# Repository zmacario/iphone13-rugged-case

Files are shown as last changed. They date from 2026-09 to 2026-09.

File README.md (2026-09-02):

# iPhone 13 Rugged Case — parametric, two-part, 3D-printable

A drop-oriented case for the **iPhone 13 (6.1", 146.7 × 71.5 × 7.65 mm)**, designed to be
printed in **PLA**. It splits into a front frame and a back plate held together by **10 M3
screws running into 10 captive nuts**, so nothing has to stretch over the phone — which is what
makes a rigid filament workable for a case at all.

Everything here is generated by one parametric FreeCAD script, which also re-verifies the model
on every run. The STLs are the output, not the source.

> **Status: printed, and the phone fits.** Both parts have been printed in PLA and the iPhone 13
> seats in them. Every opening — the four button windows, the two bottom slots and the camera —
> comes from measurements taken off printed parts on the actual phone, not from estimates. See
> [What has and hasn't been verified](#what-has-and-hasnt-been-verified) for what is still open.

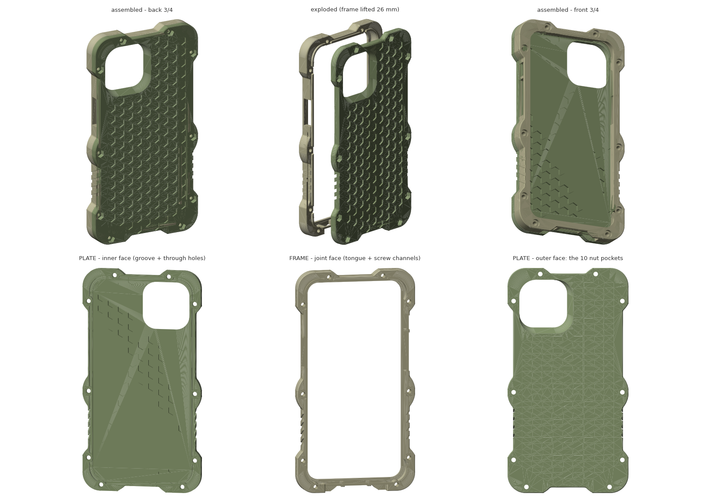
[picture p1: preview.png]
Case renders


| | |
|---|---|
| Assembled | 87.2 × 162.4 × 13.75 mm |
| Material | 60.0 cm³ ≈ **74 g** of PLA (52 g plate + 22 g frame) |
| Hardware | **10 × M3 × 10 mm button head (ISO 7380)** + **10 × M3 nut (DIN 934)** |
| Back plate | 4.0 mm in the middle, 5.0 mm around the rim |
| Side wall | 3.4 mm (2.4 mm at the grip grooves) |
| Corner shell | 4.0 mm plus a 1.6 mm internal air pocket |
| Lens recess | **2.1 mm** below the outer back face |
| Screen lip | 1.8 mm above the display |

## What you need

- ~74 g of filament (PLA works; see *On PLA* below)
- 10 × M3 × 10 mm button-head screws, ISO 7380. **Not countersunk** — a conical head wedges the
  plastic apart as you tighten it and splits thin PLA walls.
- 10 × M3 nuts, DIN 934 (2.4 mm thick, 5.5 mm across flats)
- A 2 mm hex key

## Printing

**Orientation matters and is different for each part. Getting the frame wrong is the single most
common way to ruin this print.**

| Part | File | Orientation |
|---|---|---|
| Back plate | `capa_v8_base_traseira.stl` | Back face down on the bed (honeycomb side down) |
| Front frame | `capa_v8_aro_frontal.stl` | **Upside down — front lip face on the bed** |

The frame's joint face is only 3.4 mm wide. Put that face on the bed and the first layer is a
thin 460 mm-long ring that will lift. Printed lip-down, the first layer is the 4.9 mm-wide rim
ring, and the whole part comes out without a single support.

The plate has a 1 mm skirt around its rim, so it **cannot** be printed inverted either — the
skirt ring would be the lowest feature and the central slab would be cantilevered over air.

| Setting | Value |
|---|---|
| Layer height | 0.2 mm |
| Perimeters | 3–4 |
| Infill | 25–35 % gyroid |
| PLA | 200–215 °C, bed 60 °C, fan 100 % |
| Supports | **None**, for either part |

Printed lip-down, the roofs of the button windows become bridges — the longest is **28.5 mm**
across a 3.4 mm wall. Turn bridging and full part cooling on. Any sag lands on the inner edge of
the window, which is invisible once assembled. Other bridges are short: 1.6 mm over the corner
air pockets, 6.4 mm over each honeycomb cell, 1.4 mm at the nut pocket ceiling.

### Print the test coupons first

`teste_canto_base.stl` + `teste_canto_aro.stl` are the camera corner of both parts, about
40 minutes together. That pair exercises the camera opening, the tongue-and-groove joint, one
screw with its nut and one reinforced corner. It is cheap insurance against a nine-hour print
that turns out not to close, which is exactly how the camera opening was caught.

## Assembly

1. Drop the 10 nuts into the hex pockets on the **back** of the plate. The pockets are
   deliberately tight (5.6 mm for a 5.5 mm nut); if yours come out loose, a dab of glue holds
   them — when you drive the screws, those pockets face down.
2. Drop the phone into the **frame from the back**, screen facing down.
3. Seat the plate. The tongue enters the groove and aligns everything on its own.
4. Drive the 10 screws from the **front rim**: the two mid-side ones first, then the four
   corners crosswise, then top and bottom. The threads are steel now, but what you are
   compressing is PLA — tighten until firm, not until it stops.

If the joint is tight on first assembly, raise `JOINT_GAP` from 0.15 to 0.20 and regenerate. Do
not file the tongue down; it is what keeps the two halves aligned.

## Openings

Distances from the **top** of the phone. Every one of these was measured on a printed part fitted
to the phone — the first two rounds of button windows and the first camera opening were estimates,
and all of them were wrong.

| Opening | Edges | Span |
|---|---|---|
| Mute switch (left side) | 26.00 → 36.50 mm | 10.50 mm |
| Divider between the two left windows | 36.50 → 38.50 mm | 2.00 mm |
| Volume + and − (one window) | 38.50 → 67.00 mm | 28.50 mm |
| Power / side button (right side) | 40.50 → 62.50 mm | 22.00 mm |
| Lightning (bottom, centred) | — | 16.8 × 7.0 mm |
| Speaker / microphone | ±11.0 to ±23.0 mm from centre | 12.00 mm each |
| Camera island | 1.50 mm from the top, 1.50 mm from the side | 34.5 → 38.9 mm |

Volume + and − share a single window on purpose. The real buttons are about 2 mm apart; a divider
that thin would be fragile, and if it landed even slightly off it would sit on a button.

### The camera island is a truncated pyramid

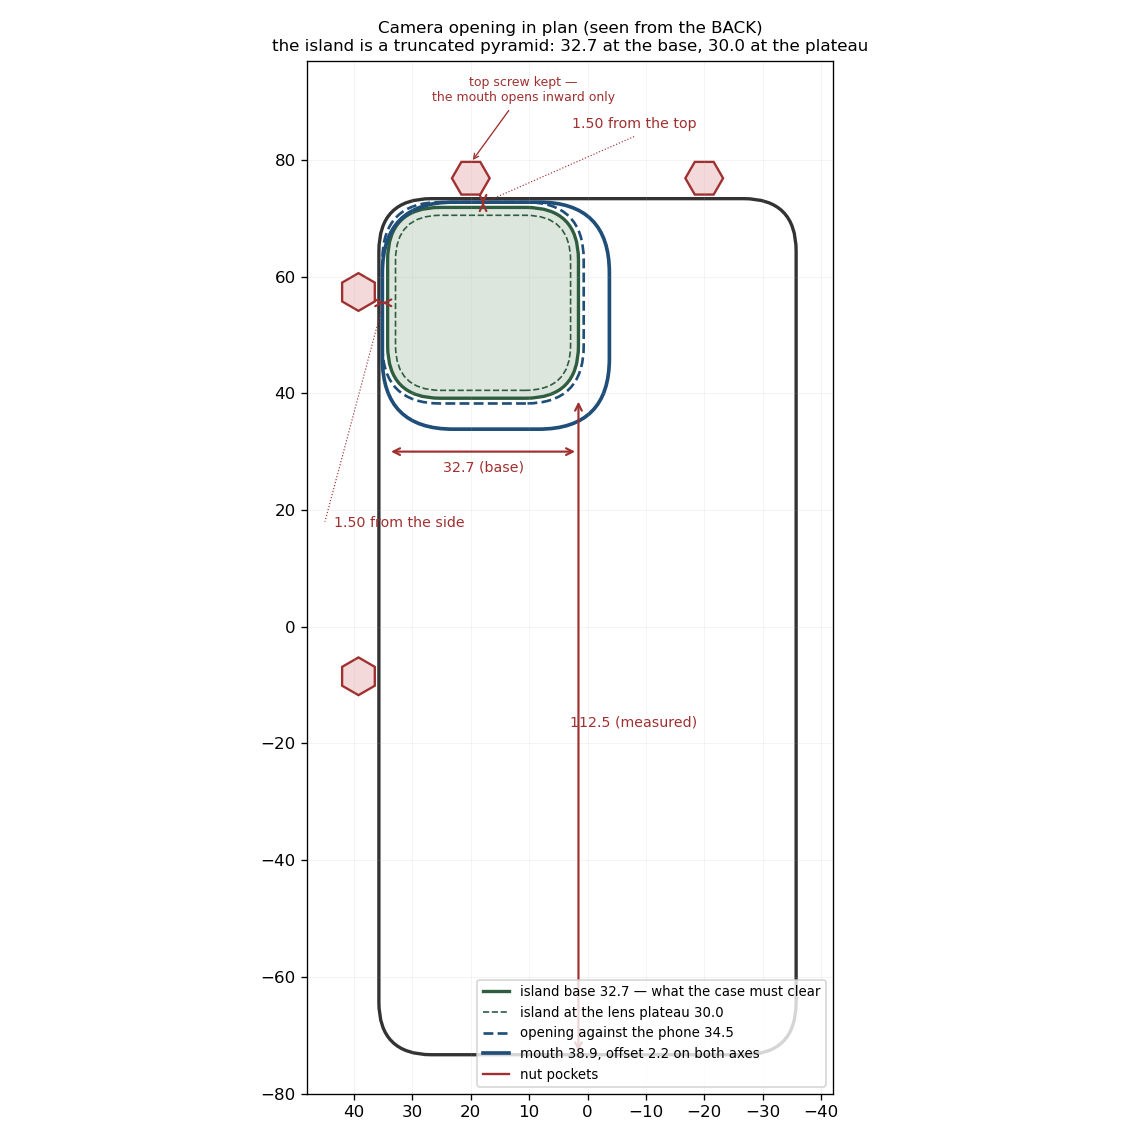
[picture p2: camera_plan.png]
Camera opening in plan


This is the part that took three attempts, and the reason is worth stating plainly: the island is
**30.0 mm square at the lens plateau but 32.7 mm at its base**, where it meets the back glass. The
case has to clear the **base**, and the plateau is the number you get if you measure the obvious
way. Modelling the plateau produced an opening that was both too small and mispositioned, and the
case would not close with the phone in it.

The three measurements close exactly, which is how the numbers were confirmed:
**112.5 + 32.7 + 1.5 = 146.7 mm**.

**The opening flares inward only, on both axes.** It is 34.5 mm against the phone and 38.9 mm at
the outer face, but the mouth is offset 2.2 mm in X *and* Y, so its outer edges sit flush with the
narrow opening's. On the two edges where the island is only 1.5 mm from the edge of the phone
there is no room to flare — that thin band is exactly what carries the corner screw and the top
screw. The mouth opens only toward the centre of the phone, which is the direction the ultra-wide
actually needs clear.

That is what kept all 10 screws. With a symmetric flare the mouth would reach y = 74.95 and eat
the nut pocket of the top screw, which starts at 74.05.

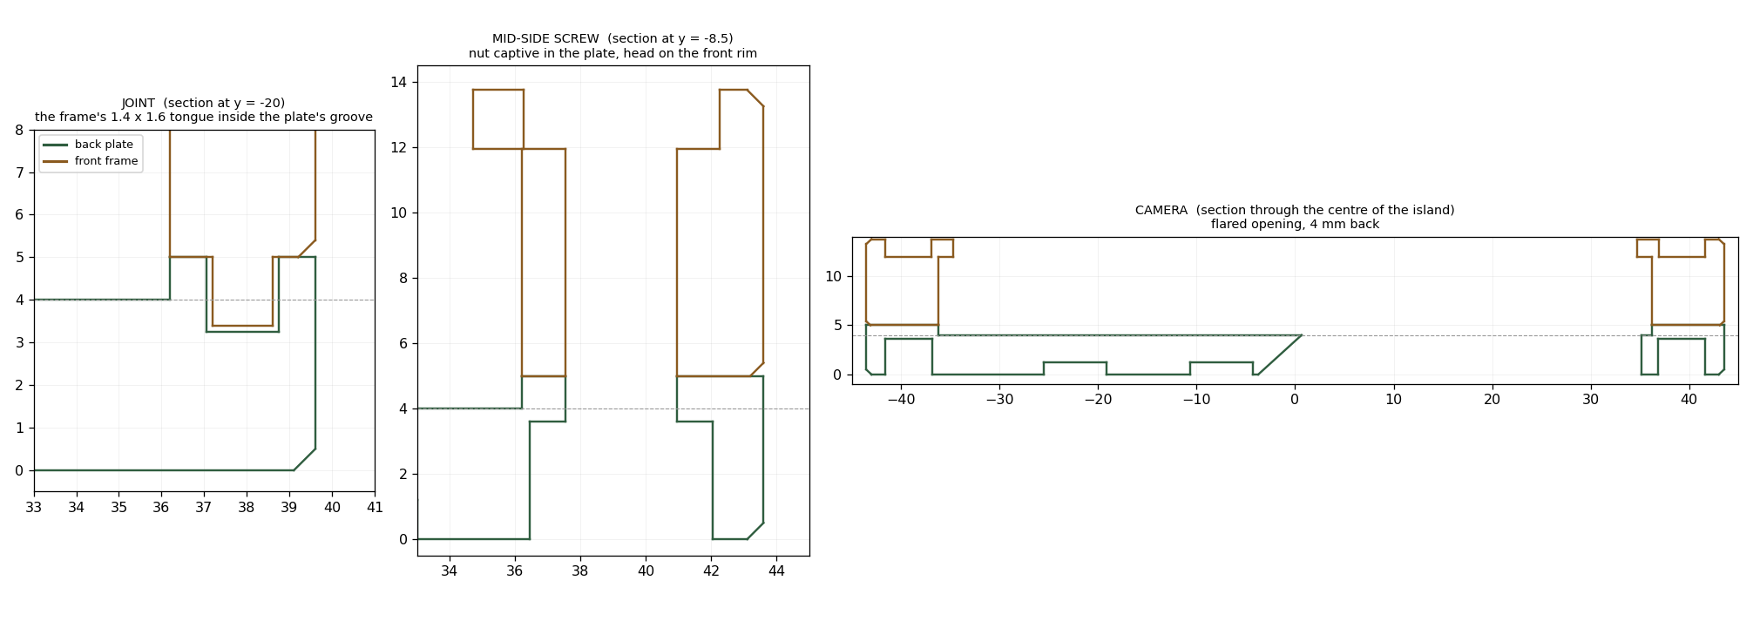
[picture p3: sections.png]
Cross-sections


The asymmetry is visible in the right-hand section above: the opening ramps out on one side and
goes straight up on the other.

**Growing the case does not help** — this was tried and measured, so you don't have to:

| `BUMP` | Case | Wall around the nut pocket |
|---|---|---|
| **4.0 (current)** | **87.2 × 162.4** | **1.2 mm** |
| 5.0 | 89.2 × 164.4 | 0.6 mm |
| 5.75 | 90.7 × 165.9 | 0.8 mm |
| 6.5 | 91.5 × 166.7 | 0.0 mm |

It is counterintuitive, and the reason is in the code: the rule that places each screw keeps it
**centred in the band of material**, so fattening the corner walks the screw outward along with
the surface instead of away from the opening — while the zone where the pad is at full thickness
*shrinks*. At `BUMP` 6.5 the case is 4.3 mm wider and the walls have gone to zero.

## What has and hasn't been verified

| | |
|---|---|
| Both parts print without supports | **yes** |
| The phone seats in the case | **yes** |
| All four button windows line up | **yes**, measured on a printed frame |
| Speaker, microphone and Lightning openings | **yes** |
| Camera opening clears the island and closes | **yes** |
| Nut pockets holding real M3 nuts | not yet confirmed |
| Head recesses taking real screws | not yet confirmed |
| Ultra-wide vignetting at 0.5× | **unverified** — see below |
| Actual drop performance | **never tested.** No one has thrown this at concrete |

The asymmetric flare is a reasoned bet, not a measurement: it assumes the ultra-wide needs
clearance toward the centre of the phone and not toward its two near edges. After assembling,
take a photo at **0.5×** and look at the corners of the frame. If it vignettes, raise `CAM_FLARE`
from 2.2 and regenerate — and then the top screw on the camera side becomes a choice rather than a
given.

The SIM tray is covered — normal for a rugged case. There is no top cutout, and **wireless
charging does not work through this case**: the back is 4.0 mm and Qi wants 3 mm or less between
the charger and the phone. That is a deliberate trade — the same 4 mm is what recesses the lenses.

## Design notes

Almost nothing here is a free choice; each dimension is pinned by something concrete. The
reasons are worth knowing before you modify anything.

**Two parts, split 1 mm above the phone's back plane.** PLA does not stretch, so a one-piece case
cannot be fitted. The phone enters the frame from the back and the plate closes it. The inverse
split (a tub plus a thin front bezel) was rejected on purpose: it would put a face-down drop onto
a thin PLA frame, which is exactly where it breaks. Here the part that takes the impact is the
frame — a closed, stiff ring.

**The plate is a shallow tray, not a flat slab.** It is 4.0 mm in the middle and 5.0 mm around
the rim. The extra millimetre is what gives the nut a ceiling to bear against, and it is only
where the screws are — the middle stays 4.0 mm, because that is what sets the lens recess. It is
added *inward*, by raising the split plane: thickening the outer face would have left the central
slab floating 1 mm above the bed.

**Thick back instead of a raised camera ring.** The lenses sit 2.1 mm below the outer back face
because the back is 4.0 mm thick and the camera island is recessed inside the opening. A raised
ring around the camera — the intuitive solution — is unprintable in the only viable orientation:
with the back on the bed, the ring becomes an isolated island on the first layer with the entire
back plate cantilevered over air.

**Tongue on the frame, groove in the plate**, 1.4 × 1.6 mm with 0.15 mm clearance per side,
running the whole perimeter. It carries the shear; the screws only clamp axially. That assignment
is deliberate — the other way round, the groove would land in the frame's 3.4 mm wall and leave
two 0.85 mm ribs in the outer skin, the worst possible place in an impact. Both tongue and groove
are interrupted in a 7 mm circle around each screw; a continuous groove would eat the very
ceiling the nut needs.

**Nut in the plate, head on the front rim.** Not an aesthetic choice. A M3 nut needs ~8.2 mm of
band and the frame wall has 7.4 mm, so the nut only fits in the solid slab of the plate — and
since head and nut sit at opposite ends of the clamp, the head has to go to the front rim. The
head recess cannot exceed 1.8 mm deep either: that is the height of the lip, and deeper breaks
into the phone cavity.

**Screw positions** are squeezed between three opposing constraints:

| Group | Position | Gap to next |
|---|---|---|
| 4 at the corners | x = ±39.25, y = ±57.35 | side: **65.85 mm** |
| 2 mid side | x = ±39.25, y = −8.50 | — |
| 2 top edge | x = ±20.00, y = +76.85 | top: **40.00 mm** |
| 2 bottom edge | x = ±30.00, y = −76.85 | bottom: **60.00 mm** |

Outward, the nut pocket is 6.5 mm corner to corner and has to stay where the corner pad is at
full thickness. Inward is the cavity wall — and right behind it, at the corners, the **air
pockets**. Along the bottom edge, the speaker and microphone slots occupy x = 11 to 23 mm. On the
bottom edge those three left no valid position at all, so the air pocket now has a **relief
around every screw**, leaving a solid pillar for the channel to pass through. The pocket survives
everywhere else in the corner, which is where impact actually lands.

The mid-side screws each carry a local 4 mm boss. It **cannot** be centred at y = 0: it would
reach into the volume-button window, and where the boss is, the wall becomes 7.4 mm — the
volume-down button would sit at the bottom of a well. At y = −8.5 it stops 1.2 mm short and the
wall at the button stays 3.4 mm.

**Corner pads with `PAD_R` = 13 mm.** The pads' outer radius used to be inherited from the body
(16.85 mm), which was never a design decision — just a consequence of offsetting the profile, and
it made the corners read as soft lobes. Making it an explicit, smaller parameter squared them off
and, as a side effect, pushed away the outer-surface curvature that was pinching the bottom
screws: their surrounding wall went from 1.00 to 1.40 mm.

**Corner air pockets**, 1.6 mm between the phone corner and a 4.0 mm shell, so the corner deforms
and absorbs instead of working as a solid block.

### Walls are measured, not calculated

Every wall around every hole is **measured on the solid**: the generator builds a ring around
each feature and tests whether it lies entirely inside the material — three measurements per
screw, on every run.

This replaced a formula, and the reason matters. A formula looks along the screw axis, and what
kills you is off the axis: the corner of the hex pocket, the curve of the pad, the air pocket
behind the cavity wall. The formula reported 1.30 mm where the real wall was 0.66 mm, and it
missed a hole that had broken into an air pocket entirely.

Current minimums: **1.35 mm** around the nut pockets (at the two screws on the camera side;
1.50-1.60 mm at the other eight), **1.45 mm** around the head recesses, **1.20 mm** around the
screw channels (at the two bottom screws; 1.40 mm at the other eight). Interference between the
two assembled parts: **0.0000 mm³**, verified by boolean on every run.

The probe used to step in 0.2 mm increments, so a real 1.35 mm wall failed the 1.4 test and was
reported as 1.20. It now steps in 0.05 mm through the range that matters. Wall figures quoted in
the version narratives above come from the coarse probe and are approximate.

### On PLA, honestly

Splitting the case solves **assembly** — you cannot fit a rigid one-piece case over a phone. It
does not solve PLA's brittleness. In a hard drop PLA tends to crack rather than absorb. The
mitigations here (corner air pockets, 4 mm corners, every sharp internal corner filleted so it is
not a stress riser) help, but they do not turn PLA into TPU.

If you want real toughness without redesigning anything: **print the frame in PETG and keep the
plate in PLA**. The frame is the part that hits the ground, and being a two-part assembly they do
not have to be the same material.

## Regenerating and customising

The geometry is not hand-modelled. `case_iphone13.py` builds it and is the file to edit.

```bash
freecadcmd case_iphone13.py       # FreeCAD 1.1+, headless
```

On macOS the binary is at `/Applications/FreeCAD.app/Contents/Resources/bin/freecadcmd`.

Every run re-verifies and prints: both parts valid and single-solid, boolean interference between
them, the three measured walls per screw, the gaps to the camera opening and the speaker slot,
whether the mid-side boss has crept into the volume window, and the thread engagement. If a
parameter change breaks one of those, the script says so instead of quietly producing a broken
part.

`preview.py`, `sections.py`, `camera_plan.py` and `corner_silhouette.py` regenerate the figures.
All four need matplotlib, and the first two also need FreeCAD's interpreter because they read the
STEP. The last two only parse the parameters out of `case_iphone13.py`, so a figure can never
quietly disagree with the model.

| I want | Change |
|---|---|
| Squarer / rounder corners | `PAD_R` (13.0; smaller is squarer — see `corner_silhouette.png`) |
| Self-tapping threads instead of nuts | `FASTENER = "autoatarraxante"` (the skirt goes with it) |
| Six screws instead of ten | `SHORT_EDGE_SCREWS = False` |
| Single piece for TPU | `TWO_PIECE = False` |
| Looser joint | `JOINT_GAP` 0.15 → 0.20 |
| Looser nut pockets | `NUT_AF` 5.6 → 5.7 |
| More lens recess | `BACK` 4.0 → 4.6 |
| Lighter | `HEX_DEPTH` 1.2 → 1.8 |
| Kill 0.5× vignetting | `CAM_FLARE` 2.2 → 3.0 (costs the top screw on the camera side) |
| Symmetric camera flare | `CAM_MOUTH_DX` / `CAM_MOUTH_DY` = 0 (same cost) |
| Looser / tighter fit | `CLR_XY` (0.45 mm per side) |
| Chunkier corners | `BUMP` 4.0 → 5.0 (read the table above first) |
| Mirror the whole case | `MIRROR = True` |

Adapting it to another phone means the block of dimensions at the top of the script — length,
width, thickness, corner radius, camera island, button positions. If you do adapt it: measure the
camera island **at its base**, not at the lens plateau.

## Files

| File | What it is |
|---|---|
| `capa_v8_base_traseira.stl` | Back plate, ready to slice |
| `capa_v8_aro_frontal.stl` | Front frame, ready to slice (**print upside down**) |
| `teste_canto_base.stl`, `teste_canto_aro.stl` | Camera-corner test coupons — print these first |
| `capa_v8_conjunto.step` | Both parts as named BRep solids, for CAD (Fusion, Onshape, SolidWorks…) |
| `capa_v8.FCStd` | FreeCAD document |
| `case_iphone13.py` | The parametric generator — the actual source |
| `preview.py`, `sections.py`, `camera_plan.py`, `corner_silhouette.py` | Figure scripts |
| `preview.png` | Six views: assembled, exploded, and each part's faces |
| `sections.png` | Cross-sections through the joint, a screw, and the camera |
| `camera_plan.png` | Camera opening in plan, with the island and the nut pockets |
| `corner_silhouette.png` | Corner silhouette for five values of `PAD_R` |

The model files carry Portuguese names, which the generator writes: `capa` = case,
`base_traseira` = back plate, `aro_frontal` = front frame, `teste_canto` = corner test.

## Licence

- **`case_iphone13.py` and the figure scripts** — [MIT](LICENSE)
- **The design** (`*.step`, `*.stl`, `*.FCStd`, renders) — [CC BY-SA 4.0](LICENSE-DESIGN.md)

You may print and sell this case; credit José Macário (@zmacario), link back here, and share
modifications of the design under the same licence. See [LICENSE-DESIGN.md](LICENSE-DESIGN.md).

Not affiliated with Apple. "iPhone" is a trademark of Apple Inc.

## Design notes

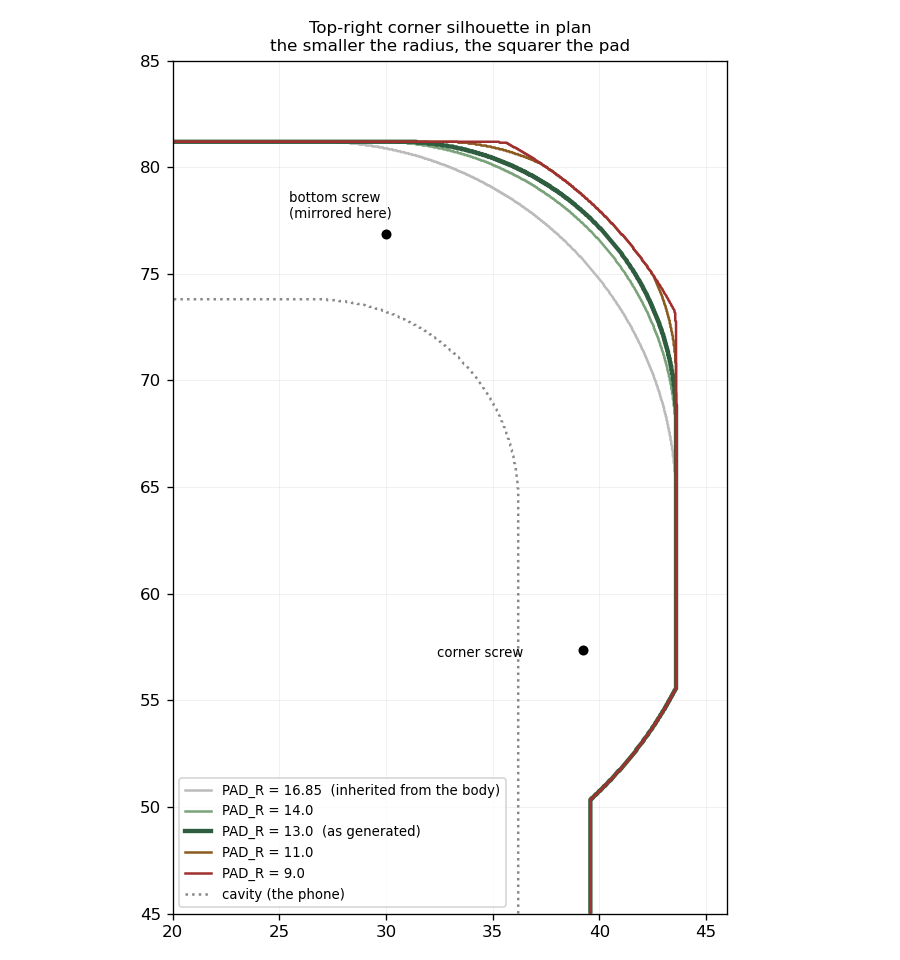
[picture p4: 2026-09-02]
corner_silhouette.png

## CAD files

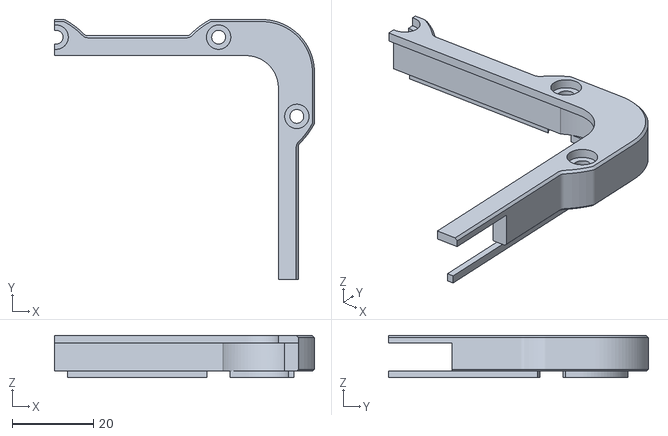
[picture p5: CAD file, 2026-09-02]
teste_canto_aro.stl
64.0 x 64.0 x 10.3

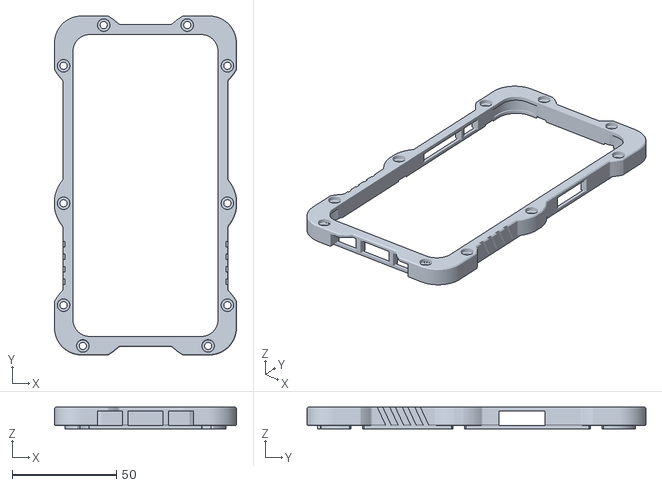
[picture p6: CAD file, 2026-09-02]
capa_v8_aro_frontal.stl
87.2 x 162.4 x 10.3

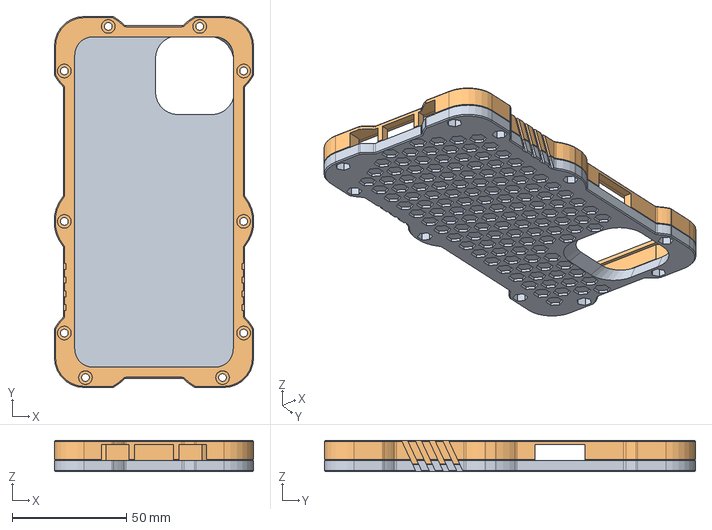
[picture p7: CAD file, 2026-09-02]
capa_v8_conjunto.step
87.2 x 162.4 x 13.8 mm

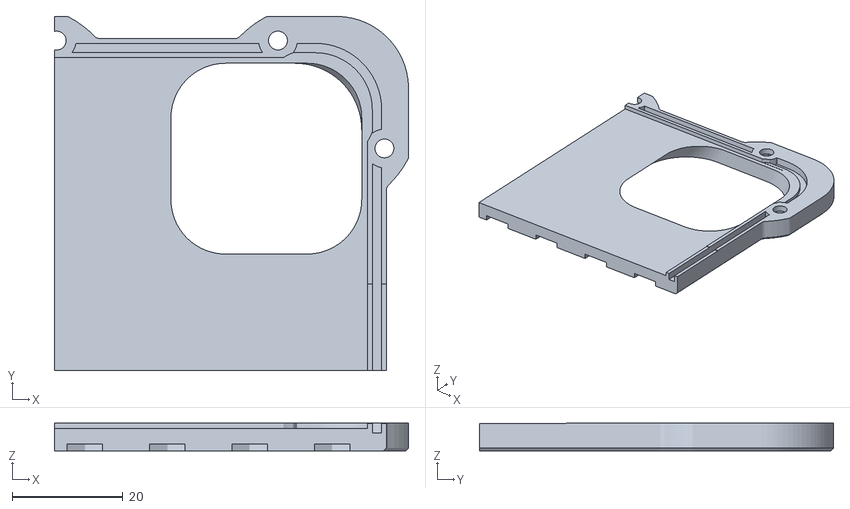
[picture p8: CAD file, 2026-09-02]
teste_canto_base.stl
64.0 x 64.0 x 5.00

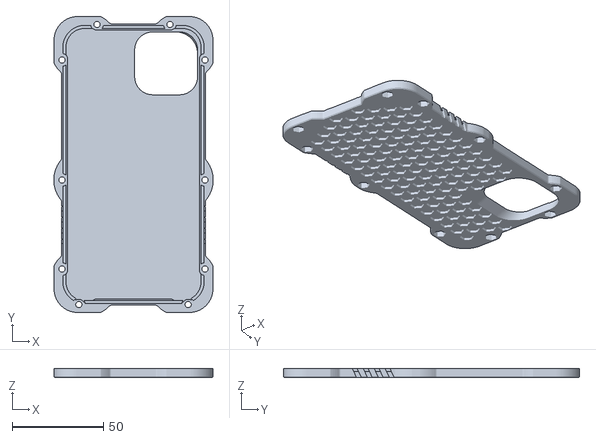
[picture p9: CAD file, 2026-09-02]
capa_v8_base_traseira.stl
87.2 x 162.4 x 5.00

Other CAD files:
capa_v8.FCStd

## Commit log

2026-08-31 Capa robusta para iPhone 13: duas peças, 10 parafusos M3, geração paramétrica
    Modelo v4 completo: aro frontal + base traseira aparafusados, projetado para
    impressão em PLA. Toda a geometria sai do case_iphone13.py (FreeCAD headless),
    que também verifica o modelo a cada rodada — interferência entre as peças,
    margens dos furos e folgas até câmera, alto-falante e janela do volume.
    Inclui STLs prontos para fatiar, STEP com os dois corpos nomeados, cupons de
    teste do canto da câmera e a documentação de impressão e montagem.
    Licença dupla: MIT para o script, CC BY-SA 4.0 para o desenho.
    [capa_v4.FCStd, capa_v4_aro_frontal.stl, capa_v4_base_traseira.stl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]
2026-08-31 Verificar interferência entre as duas peças a cada geração
    A checagem mais importante de uma peça dividida — as metades não podem ocupar
    o mesmo espaço — estava só num script auxiliar, mas o README a anunciava como
    parte do relatório do gerador. Passa a ser de verdade.
    Mudança só de relatório: os STL gerados continuam byte a byte idênticos.
2026-09-01 v6: porcas M3 embutidas, saia no perímetro e correção estrutural das furações
    Substitui a v4, que tinha uma falha: o furo-guia dos parafusos da aresta do
    fundo passava a 0,08 mm das bolsas de ar dos cantos — parede inexistente na
    prática. Passou pelas verificações da época porque a fórmula usada media apenas
    no eixo do parafuso, e o que mata está fora dele: a ponta do sextavado, a curva
    do ressalto, o vazio atrás da parede da cavidade.
    A verificação agora é feita medindo no sólido — três paredes por parafuso, a
    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
    [capa_v4.FCStd, capa_v4_aro_frontal.stl, capa_v4_base_traseira.stl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]
2026-09-02 v8: câmera medida no aparelho, todas as aberturas confirmadas na impressão
    A ilha de câmeras é tronco-piramidal: 30,0 mm no platô das lentes e 32,7 mm
    na base, que é o que a capa precisa vencer. Até aqui o modelo usava o platô,
    e o resultado foi um rasgo pequeno e deslocado 3 mm nos dois eixos — a capa
    não fechava com o aparelho dentro. As três medidas fecham exato:
    112,5 + 32,7 + 1,5 = 146,7.
    O abocardamento passou a ser assimétrico nos dois eixos. Nas duas arestas em
    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
    [capa_v6.FCStd, capa_v6_aro_frontal.stl, capa_v6_base_traseira.stl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]
2026-09-02 Medidor de paredes com passo de 0,05 mm
    O _margin andava de 0,2 em 0,2 mm, entao uma parede real de 1,35 falhava no
    teste de 1,4 e era reportada como 1,20. Era essa a divergencia entre o
    relatorio, que dizia 1,20, e o README, que dizia 1,40: nenhum dos dois estava
    errado, o medidor e que nao tinha resolucao para distinguir.
    Passo agora e de 0,05 mm na faixa que interessa, e o relatorio imprime duas
    casas. Os valores reais, iguais na geracao e conferidos parafuso a parafuso:
    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
